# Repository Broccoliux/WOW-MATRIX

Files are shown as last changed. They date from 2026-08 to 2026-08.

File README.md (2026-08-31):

# WOW MATRIX
8x8x8 LED 3D Matrix

Built by Broccoli > ME <

## what this project is

This project is my WiFi controlled 8x8x8 LED cube thing and honestly it is kinda fire

The app folder is the browser controller and the frimware folder is the ESP32 S3 code and the tiny local web server running on the board

The 3D enclosure is done and the PCB is done too the only part missing on the enclosure is the LED mounts because I am gonna add those once I print the enclosure and test the fit

The main thing still missing right now is the firmware because that is the part that actually makes the cube run for real

## repo layout

```text
WOW MATRIX/
    app/
        index html       browser UI
        script js        3D cube logic controls animations WiFi sending
        style css        page styling and LED visuals
        firmware/        another firmware folder that exists in the app area
    frimware/
        platformio ini   ESP32 S3 PlatformIO config
        src/             ESP32 source files
        data/            files served by the ESP32 web server
    CAD/               cube design files and mechanical work
    imgs/              project images
    Matrix/            KiCad project and PCB related files
```

The real firmware folder is the root frimware not app firmware and that is the one that matters for flashing and deployment

## how the web app works

The browser creates 512 LED objects in JavaScript Each LED has

```text
x = 0 to 7
y = 0 to 7
z = 0 to 7
color = RGB
```

The data is stored in this order

```text
index = z * 64 + y * 8 + x
```

This is basically a visual 3D model of the cube CSS 3D transforms place each LED dot in space and dragging the viewport rotates the whole cube around X Y and Z The LEDs are rendered as little glowing bulbs with a highlight a colored center and a dark socket behind them

## controls in the page

### bulk selection

Use the LED table checkboxes to pick a bunch of voxels choose a color and hit Apply That updates the browser model and sends the frame to the ESP32 when the cube is connected

### animations

The current animation lineup is

- Rain drops fall down the Y axis in every X Z column
- Pulse the whole cube brightens and dims with the selected animation color
- Wave brightness moves through X Y and Z together
- Bouncing Ball a bright ball travels through the cube volume
- Lightning a quick flash path jumps through multiple voxels

The animation color picker is separate from the bulk selection color because changing the bulk color should not silently change the animation color That would be weird and annoying also some animations are still a little rough and I will clean them up later

### image mapper

Use the Image Mapper to load a photo or image The browser draws it into an 8x8 canvas and reads the pixels with Canvas getImageData

There are two modes

- 3D Volume each image pixel is copied across all 8 Z layers so a full 8x8 image can use all 512 LEDs
- Front Face each image pixel only appears on the front face so it uses up to 64 LEDs

Super dark or transparent pixels stay off The original RGB values are preserved per LED so the image does not get flattened into one single color

Loading an image also stops the current animation because the image frame has to stay on the cube

## ESP32 WiFi setup

The ESP32 S3 starts its own WiFi network not the home router Very on brand for a tiny cube project

```text
WiFi name LED_Cube_Controller
Password password123
ESP32 IP 192 168 4 1
```

The ESP32 also runs a DNS server If you type a hostname while connected to the cube WiFi it gets redirected to the board which is how the captive portal works on a lot of phones

If your phone does not auto open the controller just open this manually

```text
http://192 168 4 1
```

Some phones say the WiFi has no internet That is normal Just choose stay connected anyway The cube network is local and does not need internet for the controller to work

## how the ESP32 receives a frame

The browser sends a POST request to

```text
POST /api/frame
```

The request body is base64 text After decoding it has to contain exactly

```text
512 LEDs x 3 bytes = 1536 bytes
```

The bytes are sent in this order

```text
for z 0..7
    for y 0..7
        for x 0..7
            red green blue
```

Other API routes

```text
GET /api/status checks if the ESP32 is alive
POST /api/clear turns the stored frame off
```

The browser sends frames about 30 times per second while connected That limit is intentional so dragging the cube does not spam the ESP32 with a million requests

## upload the firmware and web page

You will need VS Code the PlatformIO extension and the ESP32 platform Open the root firmware folder

```text
F:\OneDrive\Desktop\cloned repos\WOW MATRIX\frimware
```

The board config is already in platformio ini

```ini
[env esp32 s3 devkitc 1]
platform = espressif32
board = esp32 s3 devkitc 1
framework = arduino
monitor_speed = 115200
```

First upload the files in data then upload the program

```bash
cd "F:\OneDrive\Desktop\cloned repos\WOW MATRIX\frimware"
pio run -t uploadfs
pio run -t upload
```

uploadfs pushes data index html data script js and data style css into the ESP32 LittleFS storage upload flashes the C++ firmware onto the board Both are needed

If you change anything in app copy the files into frimware data again before running uploadfs

```bash
copy "F:\OneDrive\Desktop\cloned repos\WOW MATRIX\app\index html" "F:\OneDrive\Desktop\cloned repos\WOW MATRIX\frimware\data\index html"
copy "F:\OneDrive\Desktop\cloned repos\WOW MATRIX\app\script js" "F:\OneDrive\Desktop\cloned repos\WOW MATRIX\frimware\data\script js"
copy "F:\OneDrive\Desktop\cloned repos\WOW MATRIX\app\style css" "F:\OneDrive\Desktop\cloned repos\WOW MATRIX\frimware\data\style css"
```

## what is done

The 3D enclosure is done and the PCB is done

The enclosure is missing the LED mounts for now because I am going to add those once I print the enclosure and test the fit

The main thing that is still missing is the firmware because that is the part that actually makes the cube do stuff in real life

## current status

What is working right now

- 3D 512 LED browser model
- mouse and touch rotation
- individual LED selection
- bulk color selection
- rain pulse wave ball and lightning animations
- custom animation color
- local image loading and 8x8 pixel sampling
- 3D volume image mode
- ESP32 access point setup
- captive portal routes
- status frame and clear HTTP API
- LittleFS web app serving

What is still missing

- final firmware logic to drive the real cube
- testing the real cube frame order against the physical wiring
- LED mounts on the enclosure after the print test

## final vibe

This project is made by Broccoli and that is the real energy

The software side is already pretty solid and the hardware side is basically in place now The 3D enclosure and PCB are done The only real big gap left is the firmware and that is where the focus needs to be next

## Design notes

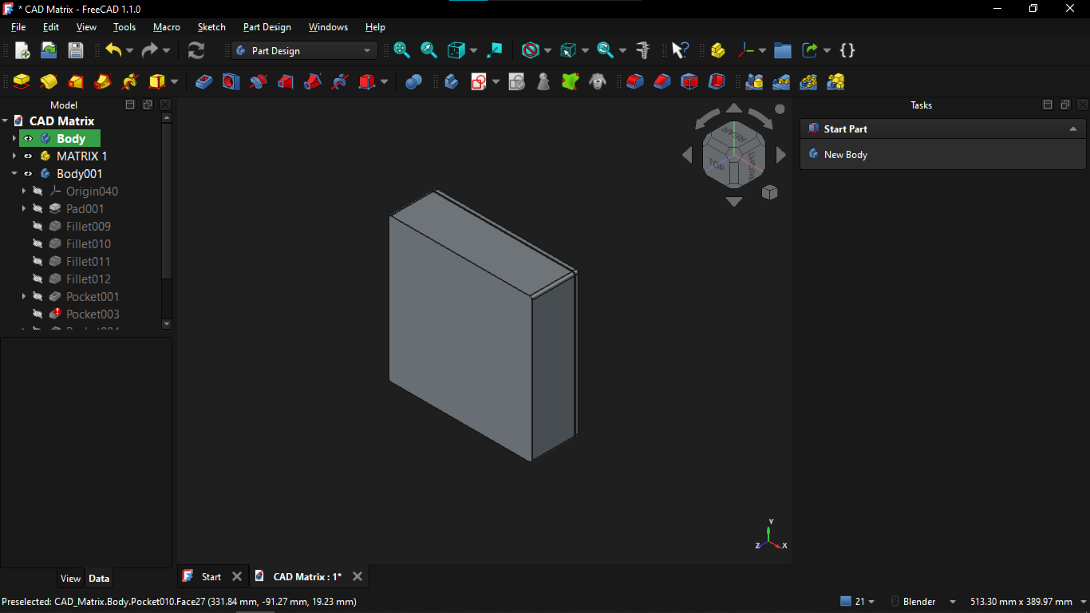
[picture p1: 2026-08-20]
imgs/CAD side.png

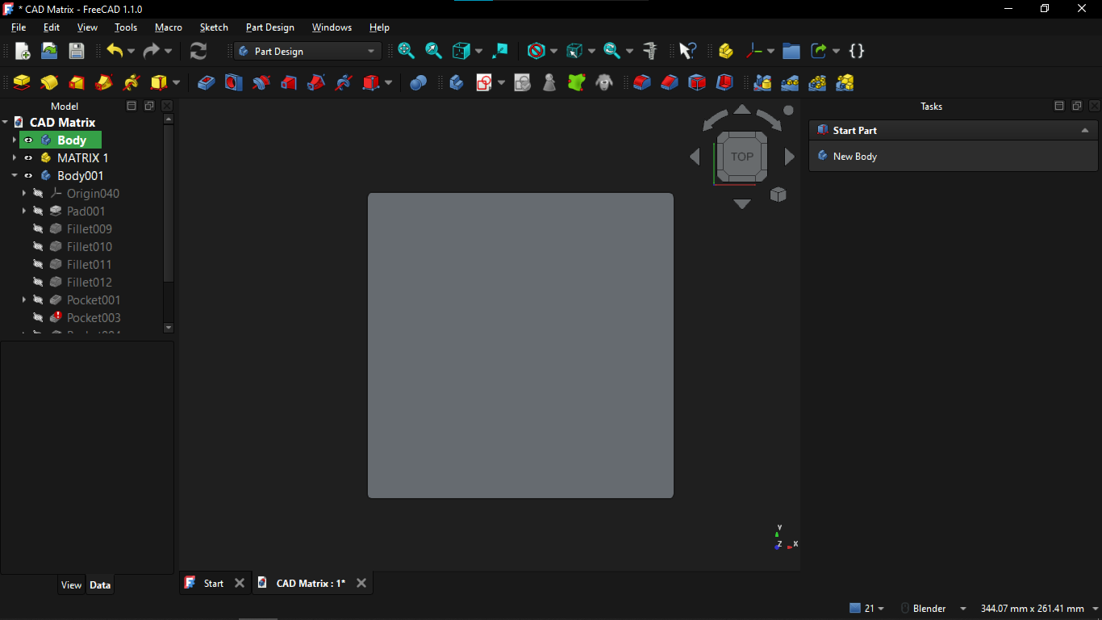
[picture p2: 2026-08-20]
imgs/CAD top.png

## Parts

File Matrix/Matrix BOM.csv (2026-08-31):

Name | price | link | amount | total
W25Q32JVSS | $1 | https://www.lcsc.com/product-detail/C82344.html | 1
ER_OLEDM0.91_1x-I2C | $4 | https://www.aliexpress.com/item/1005011783382489.html?curPageLogUid=u70x6dR5nU3C | 1
ESP32-S3 | $2.88 | https://www.lcsc.com/product-detail/rf-transceiver-ics_espressif-systems-esp32-s3_C2913192.html | 1
74HC138 | $1 | https://www.lcsc.com/product-detail/C5602.html?s_z=s_p_74HC138 | 1
74HC574N | $6 | https://www.lcsc.com/product-detail/C67579.html?s_z=n_q_74HC574N | 8
2N2219 | $7 | https://www.lcsc.com/product-detail/C37270941.html?s_z=n_q_2N2219 | 8
USB_C_Receptacle_USB2.0_16P | $0.6 | https://www.lcsc.com/product-detail/usb-connectors_shou-han-type-c16pin_C393939.html | 1
AP2112K-3.3 | $0.9 | https://www.lcsc.com/product-detail/C51118.html?s_z=n_q_AP2112K-3.3 | 1
Conn_01x08 | $5 | https://www.aliexpress.com/item/1005004839923910.html?curPageLogUid=xTL3mOFvH3BJ | 8
100 Capapstor of diff values | $5 |  | 100
100 resistor of diff vlaues | $5 |  | 100
5mm Led Diode RGB Light Emitting 4 Pin Common Anode Cathode Tricolor Multicolor Clear Diffused DIY PCB Lamp Bulb | $25 | https://www.aliexpress.com/item/1005003344498436.html?curPageLogUid=NNoxxVfOOImU | 512
 |  |  |  | $60

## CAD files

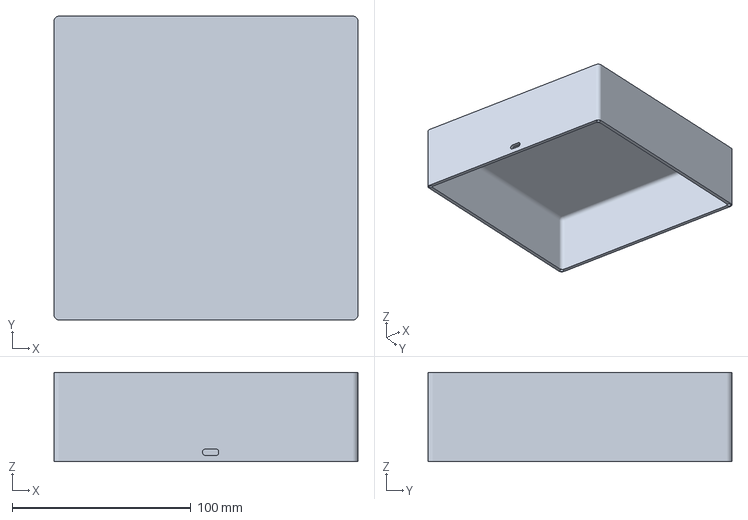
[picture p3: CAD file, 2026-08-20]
CAD/main box.3mf
170.0 x 170.0 x 50.0 mm

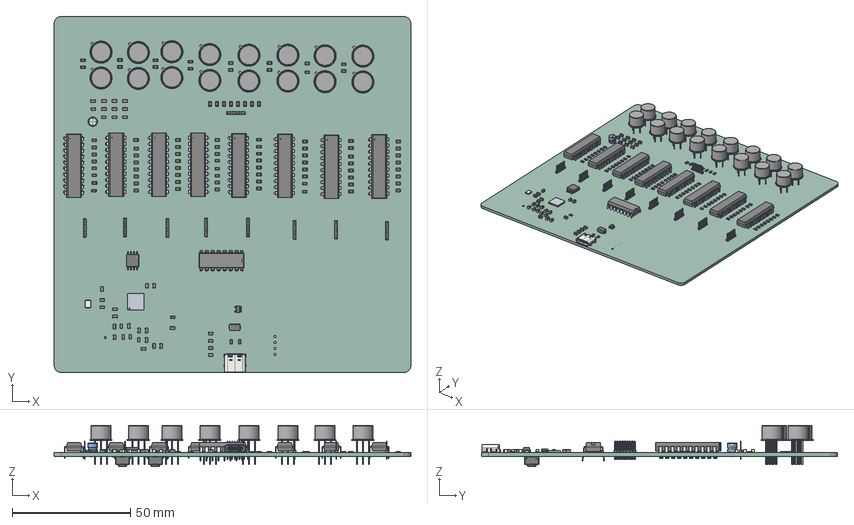
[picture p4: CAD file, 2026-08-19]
Matrix/MATRIX.step
151.0 x 150.7 x 17.5 mm
R_0805_2012Metric x 91
MATRIX 1.2.1
TO-39-3 x 16
SOT146-1_NXP x 8
C_0805_2012Metric x 32
PinHeader_1x08_P1.00mm_Vertical x 9
SOT-23-5
USB_C_Receptacle_GCT_USB4105-xx-A_16P_TopMnt_Horizontal
CP_Radial_D4.0mm_P1.50mm
L_0805_2012Metric x 4
D_SOD-923
Crystal_SMD_3225-4Pin_3.2x2.5mm
SOIC-8_5.3x5.3mm_P1.27mm
D_SMA
74HC138N_652
SW_SPST_PTS645Sx43SMTR92 x 2
Matrix_PCB

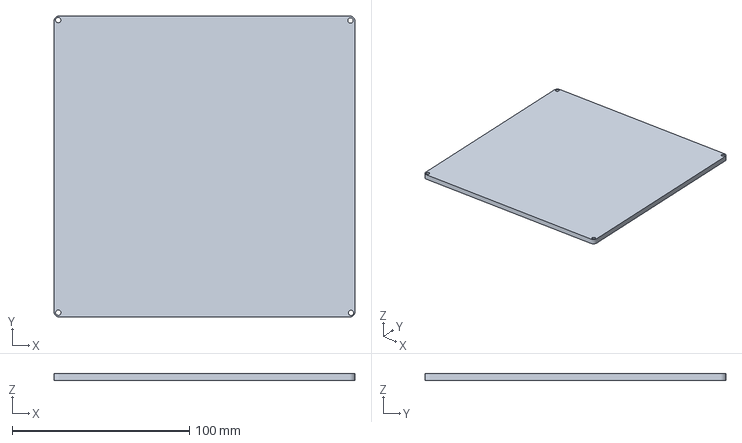
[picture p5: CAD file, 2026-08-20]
CAD/cover plate.3mf
170.0 x 170.0 x 4.00 mm

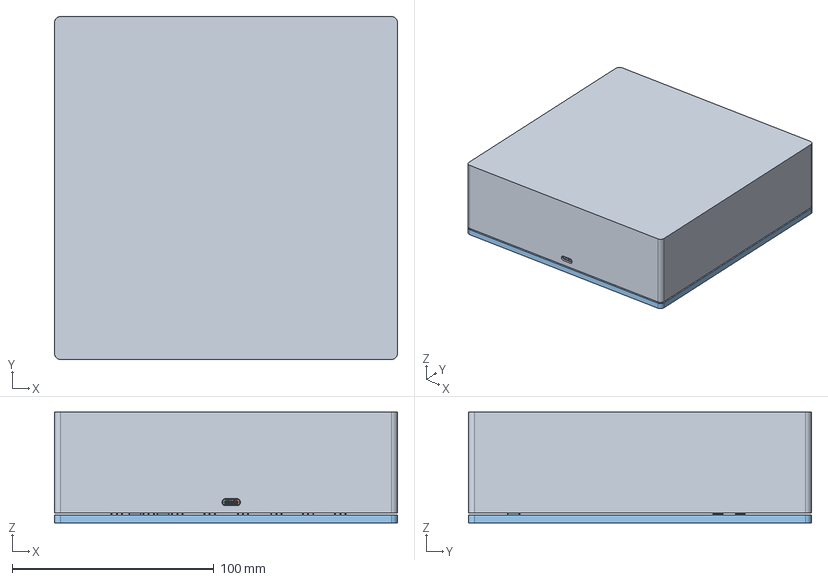
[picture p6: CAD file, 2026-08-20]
CAD/CAD Matrix.FCStd
170.0 x 170.0 x 55.0 mm
R_0805_2012Metric
MATRIX 1.2.1
MATRIX 1.2.001
MATRIX 1.2.002
MATRIX 1.2.003
MATRIX 1.2.004
MATRIX 1.2.005
MATRIX 1.2.006
MATRIX 1.2.007
MATRIX 1.2.008
MATRIX 1.2.009
MATRIX 1.2.010
MATRIX 1.2.011
MATRIX 1.2.012
MATRIX 1.2.013
MATRIX 1.2.014
MATRIX 1.2.015
MATRIX 1.2.016
MATRIX 1.2.017
MATRIX 1.2.018
MATRIX 1.2.019
MATRIX 1.2.020
MATRIX 1.2.021
MATRIX 1.2.022
MATRIX 1.2.023
MATRIX 1.2.024
MATRIX 1.2.025
MATRIX 1.2.026
MATRIX 1.2.027
MATRIX 1.2.028
MATRIX 1.2.029
MATRIX 1.2.030
MATRIX 1.2.031
MATRIX 1.2.032
MATRIX 1.2.033
MATRIX 1.2.034
MATRIX 1.2.035
MATRIX 1.2.036
MATRIX 1.2.037
MATRIX 1.2.038
MATRIX 1.2.039
MATRIX 1.2.040
MATRIX 1.2.041
MATRIX 1.2.042
MATRIX 1.2.043
MATRIX 1.2.044
MATRIX 1.2.045
MATRIX 1.2.046
MATRIX 1.2.047
MATRIX 1.2.048
MATRIX 1.2.049
MATRIX 1.2.050
MATRIX 1.2.051
MATRIX 1.2.052
MATRIX 1.2.053
MATRIX 1.2.054
MATRIX 1.2.055
MATRIX 1.2.056
MATRIX 1.2.057
MATRIX 1.2.058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

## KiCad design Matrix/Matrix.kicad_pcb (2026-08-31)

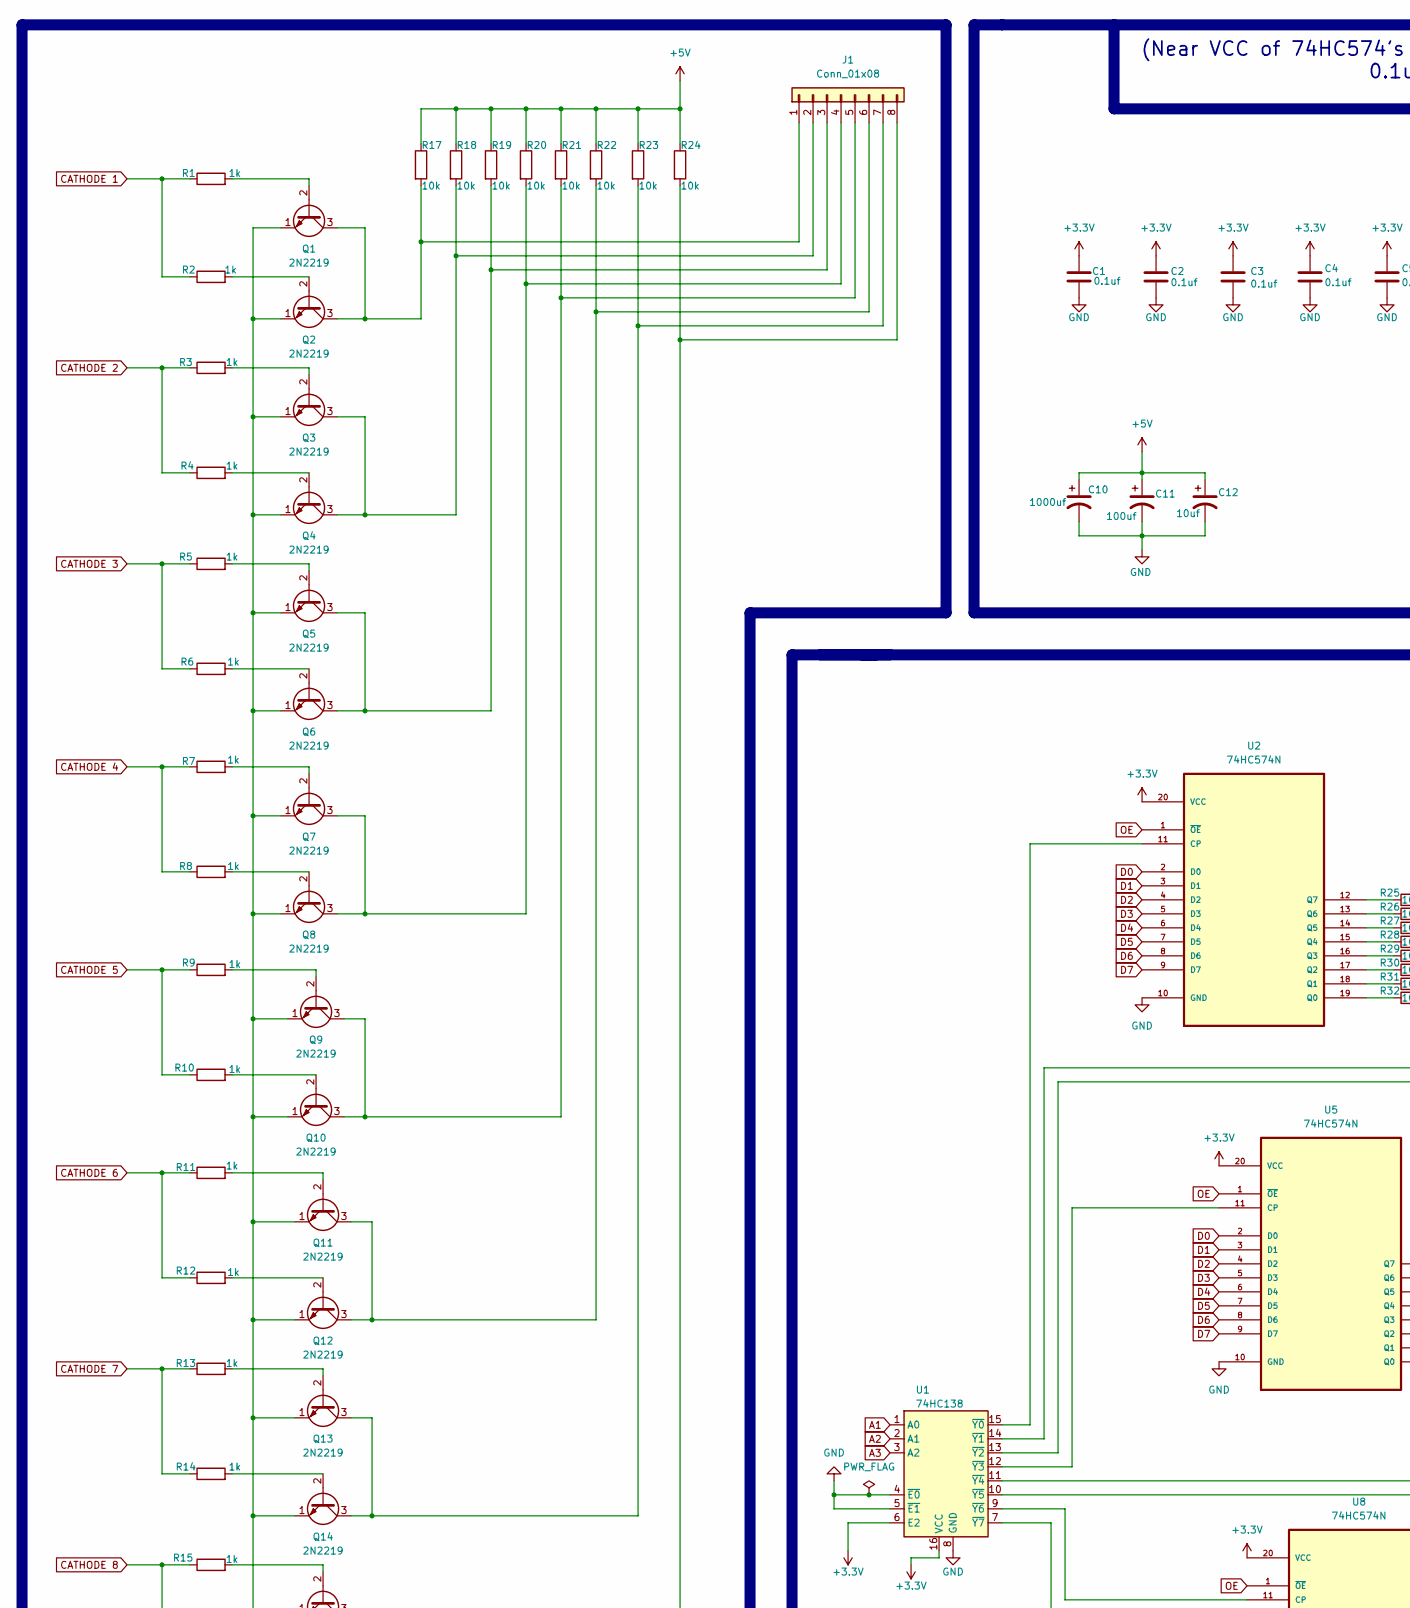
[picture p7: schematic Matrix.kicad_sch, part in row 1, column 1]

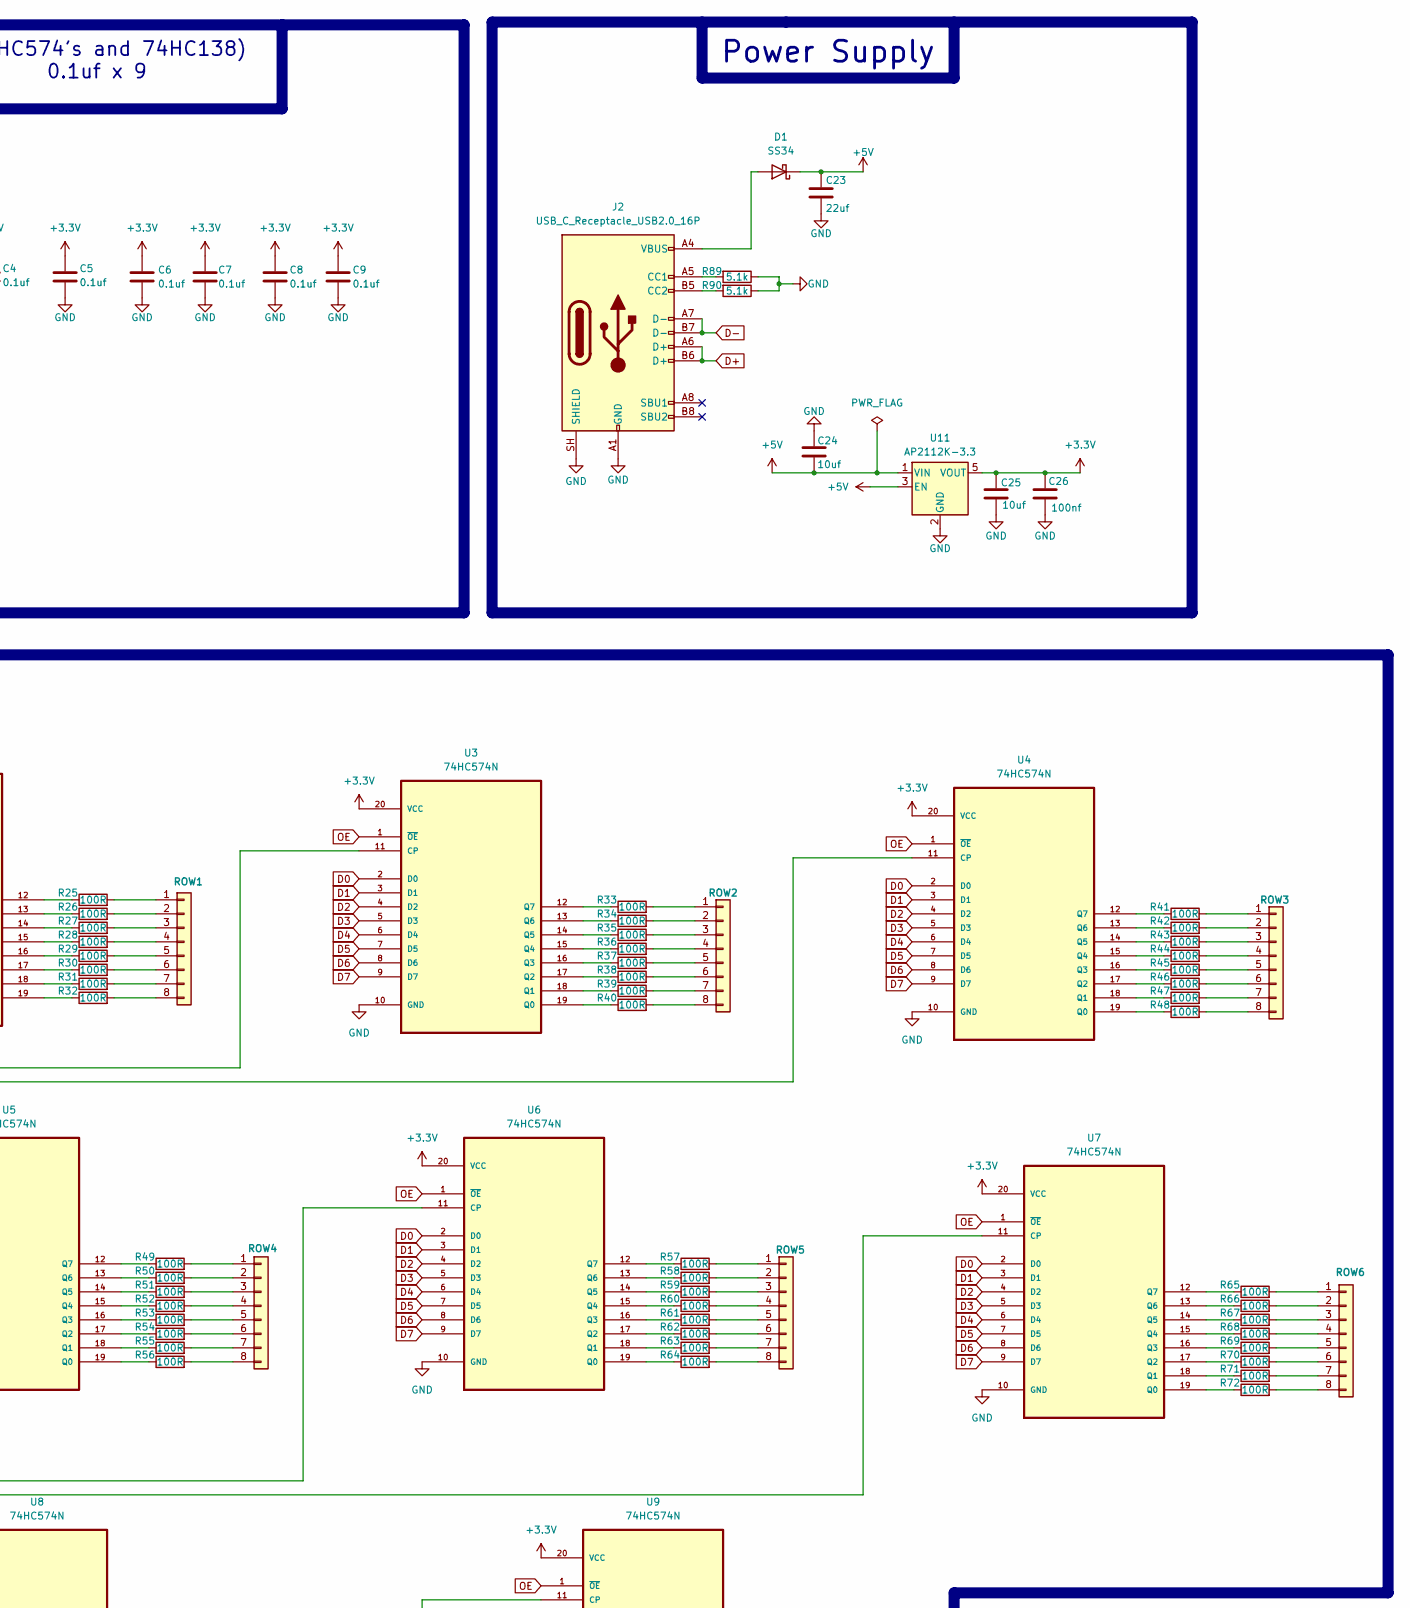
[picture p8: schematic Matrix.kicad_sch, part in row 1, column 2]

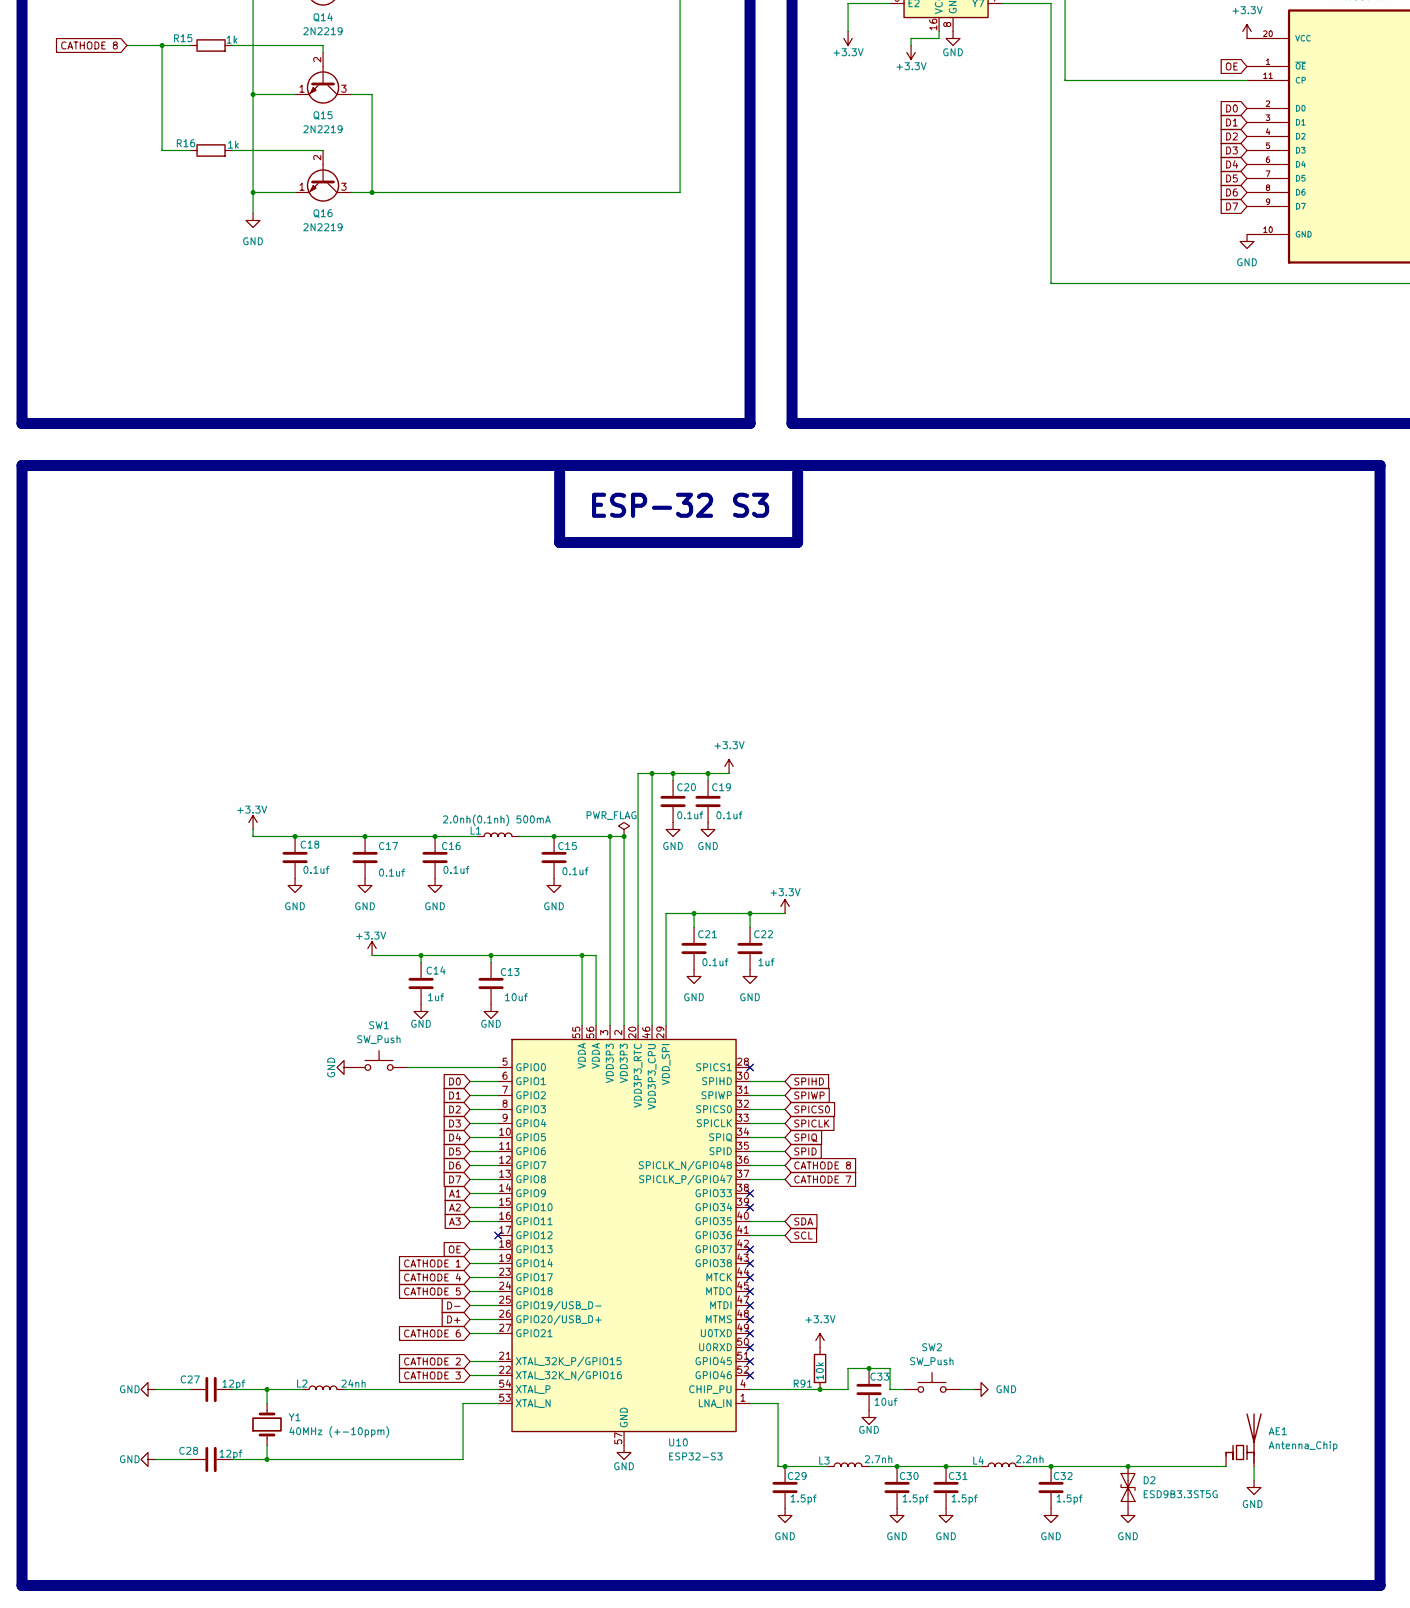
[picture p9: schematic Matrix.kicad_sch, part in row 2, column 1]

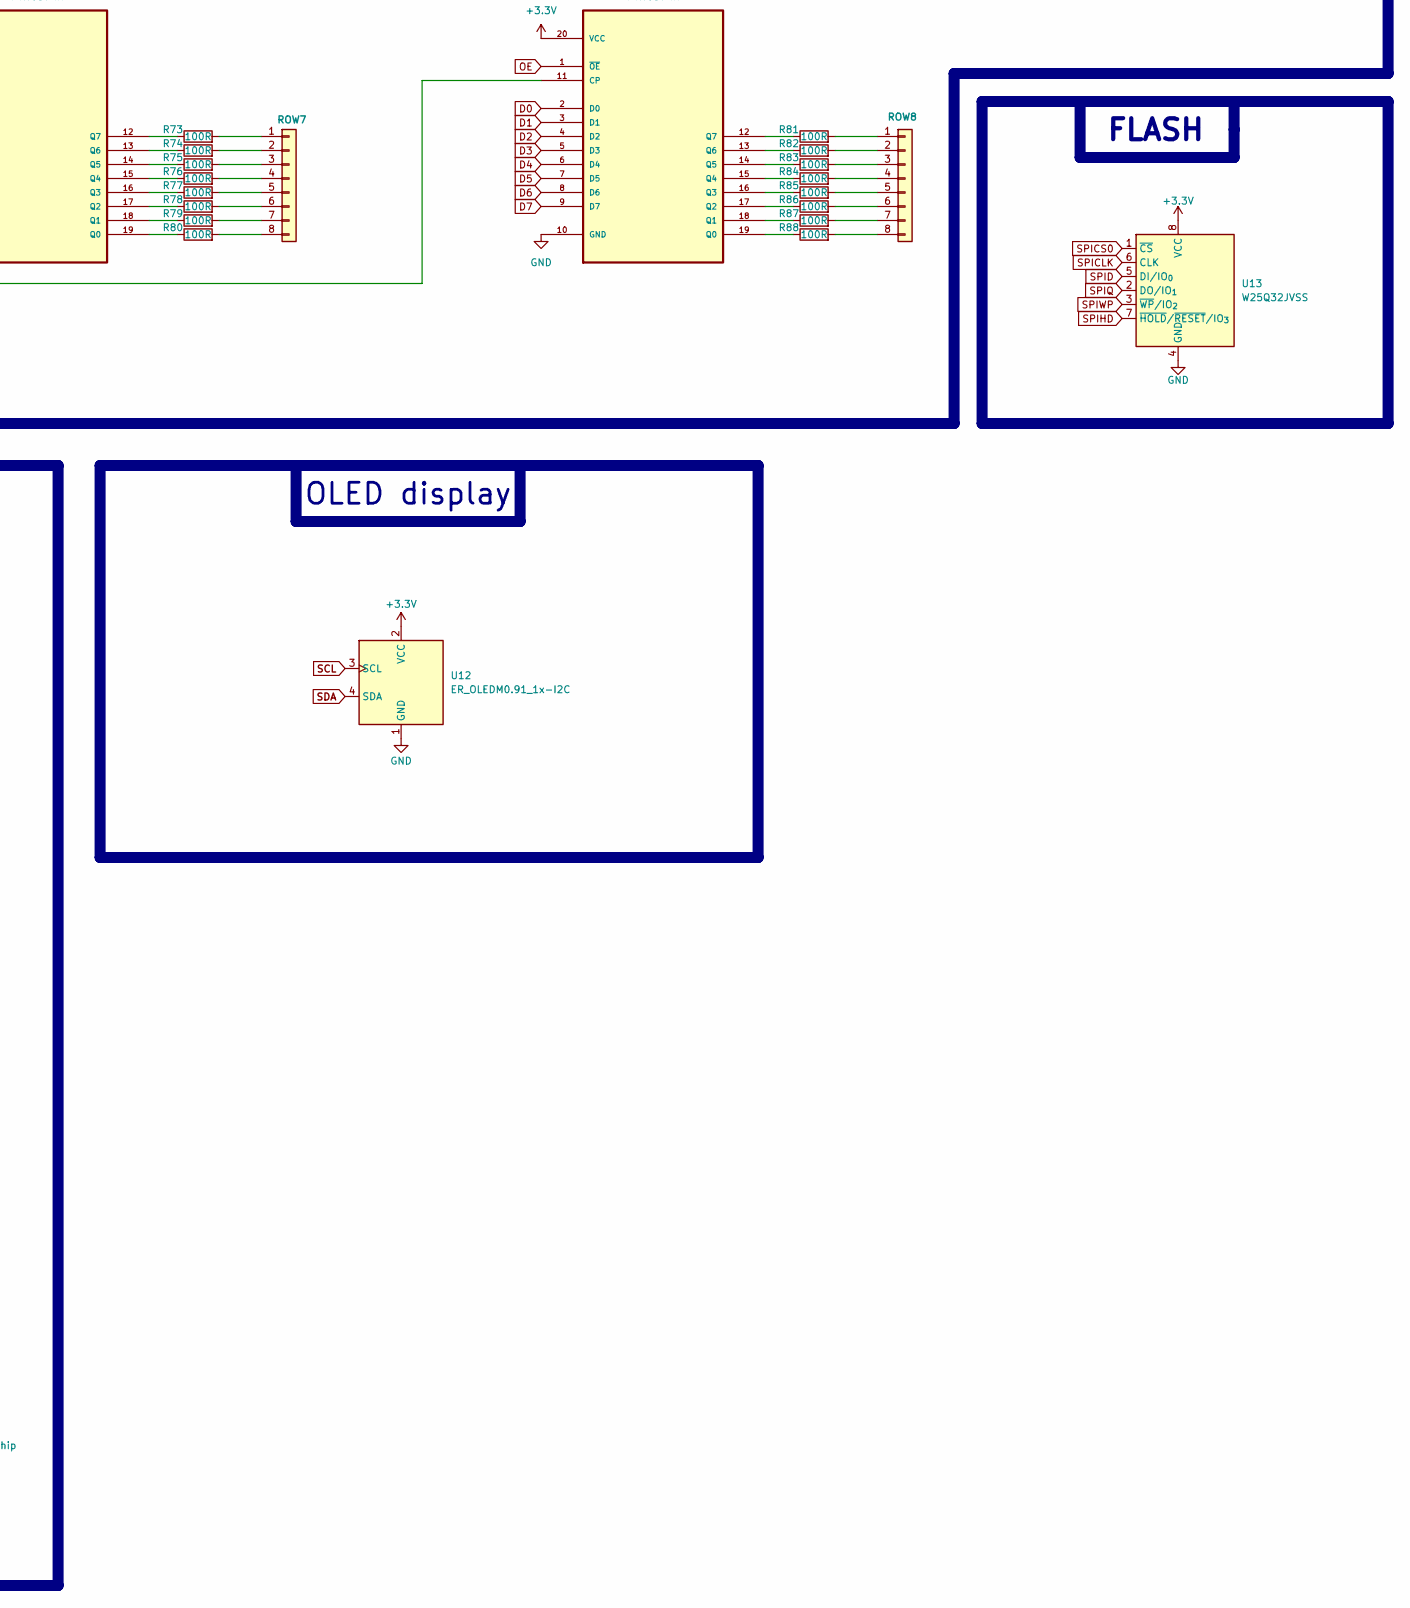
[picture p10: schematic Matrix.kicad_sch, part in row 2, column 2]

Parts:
AE1: Antenna_Chip; ANTC3216X60N
C1, C2, C3, C4, C5, C6, C7, C8, C9: 0.1uf; C_0805_2012Metric
C10: 1000uf; CP_Radial_D4.0mm_P1.50mm
C11: 100uf; C_0805_2012Metric_Pad1.18x1.45mm_HandSolder
C12, C13, C24, C25, C33: 10uf; C_0805_2012Metric_Pad1.18x1.45mm_HandSolder
C14, C22: 1uf; C_0805_2012Metric_Pad1.18x1.45mm_HandSolder
C15, C16, C17, C18, C19, C20, C21: 0.1uf; C_0805_2012Metric_Pad1.18x1.45mm_HandSolder
C23: 22uf; C_0805_2012Metric_Pad1.18x1.45mm_HandSolder
C26: 100nf; C_0805_2012Metric_Pad1.18x1.45mm_HandSolder
C27, C28: 12pf; C_0805_2012Metric_Pad1.18x1.45mm_HandSolder
C29, C30, C31, C32: 1.5pf; C_0805_2012Metric_Pad1.18x1.45mm_HandSolder
D1: SS34; D_SMA
D2: ESD9B3.3ST5G; D_SOD-923
J1: Conn_01x08; PinHeader_1x08_P1.00mm_Vertical
J2: USB_C_Receptacle_USB2.0_16P; USB_C_Receptacle_GCT_USB4105-xx-A_16P_TopMnt_Horizontal
L1: 2.0nh(0.1nh) 500mA; L_0805_2012Metric_Pad1.05x1.20mm_HandSolder
L2: 24nh; L_0805_2012Metric_Pad1.05x1.20mm_HandSolder
L3: 2.7nh; L_0805_2012Metric_Pad1.05x1.20mm_HandSolder
L4: 2.2nh; L_0805_2012Metric_Pad1.05x1.20mm_HandSolder
Q1, Q2, Q3, Q4, Q5, Q6, Q7, Q8, Q9, Q10, Q11, Q12, Q13, Q14, Q15, Q16: 2N2219; TO-39-3
R1, R2, R3, R4, R5, R6, R7, R8, R9, R10, R11, R12, R13, R14, R15, R16: 1k; R_0805_2012Metric_Pad1.20x1.40mm_HandSolder
R17, R18, R19, R20, R21, R22, R23, R24, R91: 10k; R_0805_2012Metric_Pad1.20x1.40mm_HandSolder
R25, R26, R27, R28, R29, R30, R31, R32, R33, R34, R35, R36, R37, R38, R39, R40, R41, R42, R43, R44, R45, R46, R47, R48, R49, R50, R51, R52, R53, R54, R55, R56, R57, R58, R59, R60, R61, R62, R63, R64, R65, R66, R67, R68, R69, R70, R71, R72, R73, R74, R75, R76, R77, R78, R79, R80, R81, R82, R83, R84, R85, R86, R87, R88: 100R; R_0805_2012Metric_Pad1.20x1.40mm_HandSolder
R89, R90: 5.1k; R_0805_2012Metric_Pad1.20x1.40mm_HandSolder
ROW1, ROW2, ROW3, ROW4, ROW5, ROW6, ROW7, ROW8: Conn_01x08; PinHeader_1x08_P1.00mm_Vertical
SW1, SW2: SW_Push; SW_SPST_PTS645Sx43SMTR92
U1: 74HC138; SOIC127P600X175-16N
U2, U3, U4, U5, U6, U7, U8, U9: 74HC574N; DIP254P762X420-20; MPN 74HC574N
U10: ESP32-S3; QFN-56-1EP_7x7mm_P0.4mm_EP4x4mm
U11: AP2112K-3.3; SOT-23-5
U12: ER_OLEDM0.91_1x-I2C
U13: W25Q32JVSS; SOIC-8_5.3x5.3mm_P1.27mm
Y1: 40MHz (+-10ppm); Crystal_SMD_3225-4Pin_3.2x2.5mm_HandSoldering

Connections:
+3.3V: C1.1, C2.1, C3.1, C4.1, C5.1, C6.1, C7.1, C8.1, C9.1, C13.1, C14.1, C16.1, C17.1, C18.1, C19.1, C20.1, C21.1, C22.1, C25.1, C26.1, L1.1, R91.1, U1.6 (E2), U1.16 (VCC), U2.20 (VCC), U3.20 (VCC), U4.20 (VCC), U5.20 (VCC), U6.20 (VCC), U7.20 (VCC), U8.20 (VCC), U9.20 (VCC), U10.20 (VDD3P3_RTC), U10.29 (VDD_SPI), U10.46 (VDD3P3_CPU), U10.55 (VDDA), U10.56 (VDDA), U11.5 (VOUT), U12.2 (VCC), U13.8 (VCC)
+5V: C10.1, C11.1, C12.1, C23.1, C24.2, D1.1 (K), R17.1, R18.1, R19.1, R20.1, R21.1, R22.1, R23.1, R24.1, U11.1 (VIN), U11.3 (EN)
A1: U1.1 (A0), U10.14 (GPIO9)
A2: U1.2 (A1), U10.15 (GPIO10)
A3: U1.3 (A2), U10.16 (GPIO11)
CATHODE 1: R1.1, R2.1, U10.19 (GPIO14)
CATHODE 2: R3.1, R4.1, U10.21 (XTAL_32K_P/GPIO15)
CATHODE 3: R5.1, R6.1, U10.22 (XTAL_32K_N/GPIO16)
CATHODE 4: R7.1, R8.1, U10.23 (GPIO17)
CATHODE 5: R9.1, R10.1, U10.24 (GPIO18)
CATHODE 6: R11.1, R12.1, U10.27 (GPIO21)
CATHODE 7: R13.1, R14.1, U10.37 (SPICLK_P/GPIO47)
CATHODE 8: R15.1, R16.1, U10.36 (SPICLK_N/GPIO48)
D0: U2.2 (D0), U3.2 (D0), U4.2 (D0), U5.2 (D0), U6.2 (D0), U7.2 (D0), U8.2 (D0), U9.2 (D0), U10.6 (GPIO1)
D1: U2.3 (D1), U3.3 (D1), U4.3 (D1), U5.3 (D1), U6.3 (D1), U7.3 (D1), U8.3 (D1), U9.3 (D1), U10.7 (GPIO2)
D2: U2.4 (D2), U3.4 (D2), U4.4 (D2), U5.4 (D2), U6.4 (D2), U7.4 (D2), U8.4 (D2), U9.4 (D2), U10.8 (GPIO3)
D3: U2.5 (D3), U3.5 (D3), U4.5 (D3), U5.5 (D3), U6.5 (D3), U7.5 (D3), U8.5 (D3), U9.5 (D3), U10.9 (GPIO4)
D4: U2.6 (D4), U3.6 (D4), U4.6 (D4), U5.6 (D4), U6.6 (D4), U7.6 (D4), U8.6 (D4), U9.6 (D4), U10.10 (GPIO5)
D5: U2.7 (D5), U3.7 (D5), U4.7 (D5), U5.7 (D5), U6.7 (D5), U7.7 (D5), U8.7 (D5), U9.7 (D5), U10.11 (GPIO6)
D6: U2.8 (D6), U3.8 (D6), U4.8 (D6), U5.8 (D6), U6.8 (D6), U7.8 (D6), U8.8 (D6), U9.8 (D6), U10.12 (GPIO7)
D7: U2.9 (D7), U3.9 (D7), U4.9 (D7), U5.9 (D7), U6.9 (D7), U7.9 (D7), U8.9 (D7), U9.9 (D7), U10.13 (GPIO8)
D+: J2.A6 (D+), J2.B6 (D+), U10.26 (GPIO20/USB_D+)
D-: J2.A7 (D-), J2.B7 (D-), U10.25 (GPIO19/USB_D-)
GND: AE1.2 (PCB_Trace), C1.2, C2.2, C3.2, C4.2, C5.2, C6.2, C7.2, C8.2, C9.2, C10.2, C11.2, C12.2, C13.2, C14.2, C15.2, C16.2, C17.2, C18.2, C19.2, C20.2, C21.2, C22.2, C23.2, C24.1, C25.2, C26.2, C27.1, C28.1, C29.2, C30.2, C31.2, C32.2, C33.2, D2.1 (A1), J2.A1 (GND), J2.A12 (GND), J2.B1 (GND), J2.B12 (GND), J2.SH (SHIELD), Q1.1 (E), Q2.1 (E), Q3.1 (E), Q4.1 (E), Q5.1 (E), Q6.1 (E), Q7.1 (E), Q8.1 (E), Q9.1 (E), Q10.1 (E), Q11.1 (E), Q12.1 (E), Q13.1 (E), Q14.1 (E), Q15.1 (E), Q16.1 (E), R89.1, R90.1, SW1.1, SW2.2, U1.4 (~E0), U1.5 (~E1), U1.8 (GND), U2.10 (GND), U3.10 (GND), U4.10 (GND), U5.10 (GND), U6.10 (GND), U7.10 (GND), U8.10 (GND), U9.10 (GND), U10.57 (GND), U11.2 (GND), U12.1 (GND), U13.4 (GND)
unnamed: AE1.1 (FEED), C32.1, D2.2 (A2), L4.2
unnamed: C15.1, L1.2, U10.2 (VDD3P3), U10.3 (VDD3P3)
unnamed: C27.2, L2.1, Y1.2
unnamed: C30.1, C31.1, L3.2, L4.1
unnamed: D1.2 (A), J2.A4 (VBUS), J2.A9 (VBUS), J2.B4 (VBUS), J2.B9 (VBUS)
unnamed: J1.1, Q1.3 (C), Q2.3 (C), R17.2
unnamed: J1.2, Q3.3 (C), Q4.3 (C), R18.2
unnamed: J1.3, Q5.3 (C), Q6.3 (C), R19.2
unnamed: J1.4, Q7.3 (C), Q8.3 (C), R20.2
unnamed: J1.5, Q9.3 (C), Q10.3 (C), R21.2
unnamed: J1.6, Q11.3 (C), Q12.3 (C), R22.2
unnamed: J1.7, Q13.3 (C), Q14.3 (C), R23.2
unnamed: J1.8, Q15.3 (C), Q16.3 (C), R24.2
unnamed: J2.A5 (CC1), R89.2
unnamed: J2.B5 (CC2), R90.2
unnamed: Q1.2 (B), R1.2
unnamed: Q2.2 (B), R2.2
unnamed: Q3.2 (B), R3.2
unnamed: Q4.2 (B), R4.2
unnamed: Q5.2 (B), R5.2
unnamed: Q6.2 (B), R6.2
unnamed: Q7.2 (B), R7.2
unnamed: Q8.2 (B), R8.2
unnamed: Q9.2 (B), R9.2
unnamed: Q10.2 (B), R10.2
unnamed: Q11.2 (B), R11.2
unnamed: Q12.2 (B), R12.2
unnamed: Q13.2 (B), R13.2
unnamed: Q14.2 (B), R14.2
unnamed: Q15.2 (B), R15.2
unnamed: Q16.2 (B), R16.2
unnamed: R25.2, ROW1.1
unnamed: R26.2, ROW1.2
unnamed: R27.2, ROW1.3
unnamed: R28.2, ROW1.4
unnamed: R29.2, ROW1.5
unnamed: R30.2, ROW1.6
unnamed: R31.2, ROW1.7
unnamed: R32.2, ROW1.8
unnamed: R33.2, ROW2.1
unnamed: R34.2, ROW2.2
unnamed: R35.2, ROW2.3
unnamed: R36.2, ROW2.4
unnamed: R37.2, ROW2.5
unnamed: R38.2, ROW2.6
unnamed: R39.2, ROW2.7
unnamed: R40.2, ROW2.8
unnamed: R41.2, ROW3.1
unnamed: R42.2, ROW3.2
unnamed: R43.2, ROW3.3
unnamed: R44.2, ROW3.4
unnamed: R45.2, ROW3.5
unnamed: R46.2, ROW3.6
unnamed: R47.2, ROW3.7
unnamed: R48.2, ROW3.8
unnamed: R49.2, ROW4.1
unnamed: R50.2, ROW4.2
unnamed: R51.2, ROW4.3
unnamed: R52.2, ROW4.4
unnamed: R53.2, ROW4.5
unnamed: R54.2, ROW4.6
unnamed: R55.2, ROW4.7
unnamed: R56.2, ROW4.8
unnamed: R57.2, ROW5.1
unnamed: R58.2, ROW5.2
unnamed: R59.2, ROW5.3
unnamed: R60.2, ROW5.4
unnamed: R61.2, ROW5.5
unnamed: R62.2, ROW5.6
unnamed: R63.2, ROW5.7
unnamed: R64.2, ROW5.8
unnamed: R65.2, ROW6.1
unnamed: R66.2, ROW6.2
unnamed: R67.2, ROW6.3
unnamed: R68.2, ROW6.4
unnamed: R69.2, ROW6.5
unnamed: R70.2, ROW6.6
unnamed: R71.2, ROW6.7
unnamed: R72.2, ROW6.8
unnamed: R73.2, ROW7.1
unnamed: R74.2, ROW7.2
unnamed: R75.2, ROW7.3
unnamed: R76.2, ROW7.4
unnamed: R77.2, ROW7.5
unnamed: R78.2, ROW7.6
unnamed: R79.2, ROW7.7
unnamed: R80.2, ROW7.8
unnamed: R81.2, ROW8.1
unnamed: R82.2, ROW8.2
unnamed: R83.2, ROW8.3
unnamed: R84.2, ROW8.4
unnamed: R85.2, ROW8.5
unnamed: R86.2, ROW8.6
unnamed: R87.2, ROW8.7
unnamed: R88.2, ROW8.8
unnamed: U1.15 (~Y0), U2.11 (CP)
unnamed: U1.14 (~Y1), U3.11 (CP)
unnamed: U1.13 (~Y2), U4.11 (CP)
unnamed: U1.12 (~Y3), U5.11 (CP)
unnamed: U1.11 (~Y4), U6.11 (CP)
unnamed: U1.10 (~Y5), U7.11 (CP)
unnamed: U1.9 (~Y6), U8.11 (CP)
unnamed: U1.7 (~Y7), U9.11 (CP)
unnamed: R32.1, U2.19 (Q0)
unnamed: R31.1, U2.18 (Q1)
unnamed: R30.1, U2.17 (Q2)
unnamed: R29.1, U2.16 (Q3)
unnamed: R28.1, U2.15 (Q4)
unnamed: R27.1, U2.14 (Q5)
unnamed: R26.1, U2.13 (Q6)
unnamed: R25.1, U2.12 (Q7)
unnamed: R40.1, U3.19 (Q0)
unnamed: R39.1, U3.18 (Q1)
unnamed: R38.1, U3.17 (Q2)
unnamed: R37.1, U3.16 (Q3)
unnamed: R36.1, U3.15 (Q4)
unnamed: R35.1, U3.14 (Q5)
unnamed: R34.1, U3.13 (Q6)
unnamed: R33.1, U3.12 (Q7)
unnamed: R48.1, U4.19 (Q0)
unnamed: R47.1, U4.18 (Q1)
unnamed: R46.1, U4.17 (Q2)
unnamed: R45.1, U4.16 (Q3)
unnamed: R44.1, U4.15 (Q4)
unnamed: R43.1, U4.14 (Q5)
unnamed: R42.1, U4.13 (Q6)
unnamed: R41.1, U4.12 (Q7)
unnamed: R56.1, U5.19 (Q0)
unnamed: R55.1, U5.18 (Q1)
unnamed: R54.1, U5.17 (Q2)
unnamed: R53.1, U5.16 (Q3)
unnamed: R52.1, U5.15 (Q4)
unnamed: R51.1, U5.14 (Q5)
unnamed: R50.1, U5.13 (Q6)
unnamed: R49.1, U5.12 (Q7)
unnamed: R64.1, U6.19 (Q0)
unnamed: R63.1, U6.18 (Q1)
unnamed: R62.1, U6.17 (Q2)
unnamed: R61.1, U6.16 (Q3)
unnamed: R60.1, U6.15 (Q4)
unnamed: R59.1, U6.14 (Q5)
unnamed: R58.1, U6.13 (Q6)
unnamed: R57.1, U6.12 (Q7)
unnamed: R72.1, U7.19 (Q0)
unnamed: R71.1, U7.18 (Q1)
unnamed: R70.1, U7.17 (Q2)
unnamed: R69.1, U7.16 (Q3)
unnamed: R68.1, U7.15 (Q4)
unnamed: R67.1, U7.14 (Q5)
unnamed: R66.1, U7.13 (Q6)
unnamed: R65.1, U7.12 (Q7)
unnamed: R80.1, U8.19 (Q0)
unnamed: R79.1, U8.18 (Q1)
unnamed: R78.1, U8.17 (Q2)
unnamed: R77.1, U8.16 (Q3)
unnamed: R76.1, U8.15 (Q4)
unnamed: R75.1, U8.14 (Q5)
unnamed: R74.1, U8.13 (Q6)
unnamed: R73.1, U8.12 (Q7)
unnamed: R88.1, U9.19 (Q0)
unnamed: R87.1, U9.18 (Q1)
unnamed: R86.1, U9.17 (Q2)
unnamed: R85.1, U9.16 (Q3)
unnamed: R84.1, U9.15 (Q4)
unnamed: R83.1, U9.14 (Q5)
unnamed: R82.1, U9.13 (Q6)
unnamed: R81.1, U9.12 (Q7)
unnamed: C33.1, R91.2, SW2.1, U10.4 (CHIP_PU)
unnamed: SW1.2, U10.5 (GPIO0)
unnamed: C29.1, L3.1, U10.1 (LNA_IN)
unnamed: C28.2, U10.53 (XTAL_N), Y1.1
unnamed: L2.2, U10.54 (XTAL_P)
OE: U2.1 (~OE), U3.1 (~OE), U4.1 (~OE), U5.1 (~OE), U6.1 (~OE), U7.1 (~OE), U8.1 (~OE), U9.1 (~OE), U10.18 (GPIO13)
SCL: U10.41 (GPIO36), U12.3 (SCL)
SDA: U10.40 (GPIO35), U12.4 (SDA)
SPICLK: U10.33 (SPICLK), U13.6 (CLK)
SPICS0: U10.32 (SPICS0), U13.1 (~CS)
SPID: U10.35 (SPID), U13.5 (DI/IO_{0})
SPIHD: U10.30 (SPIHD), U13.7 (~HOLD/~RESET/IO_{3})
SPIQ: U10.34 (SPIQ), U13.2 (DO/IO_{1})
SPIWP: U10.31 (SPIWP), U13.3 (~WP/IO_{2})

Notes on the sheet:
(Near VCC of 74HC574's and 74HC138) 0.1uf x 9
Power Supply
FLASH
ESP-32 S3
OLED display

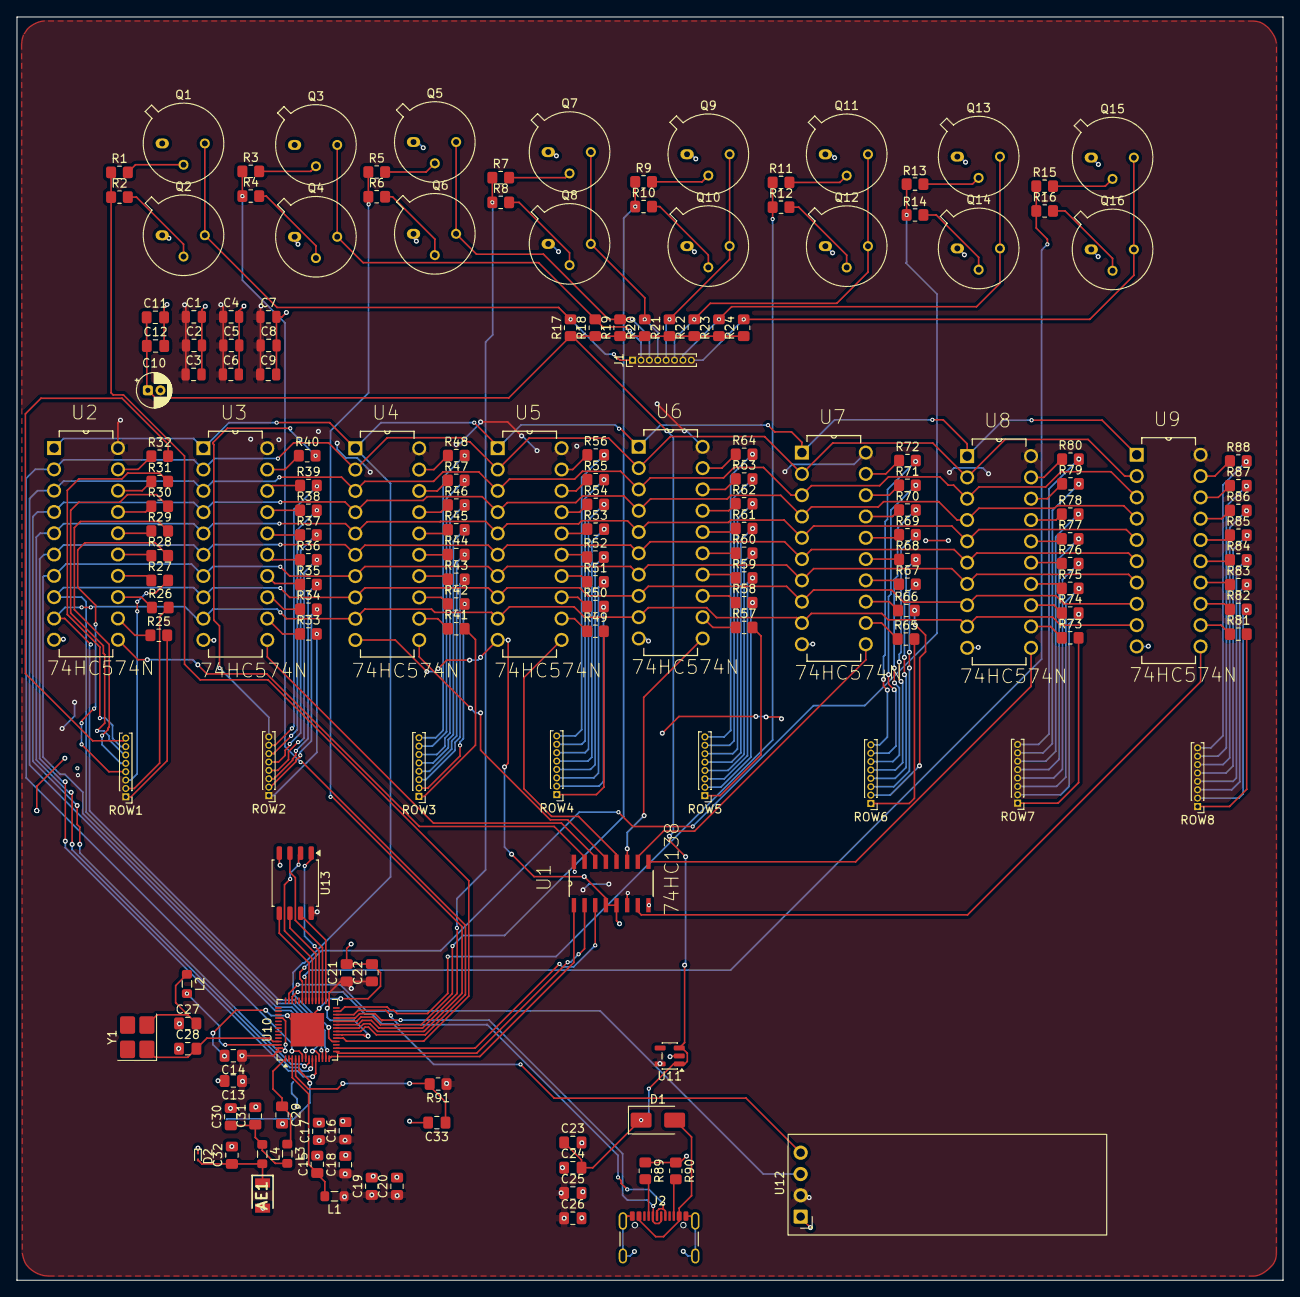
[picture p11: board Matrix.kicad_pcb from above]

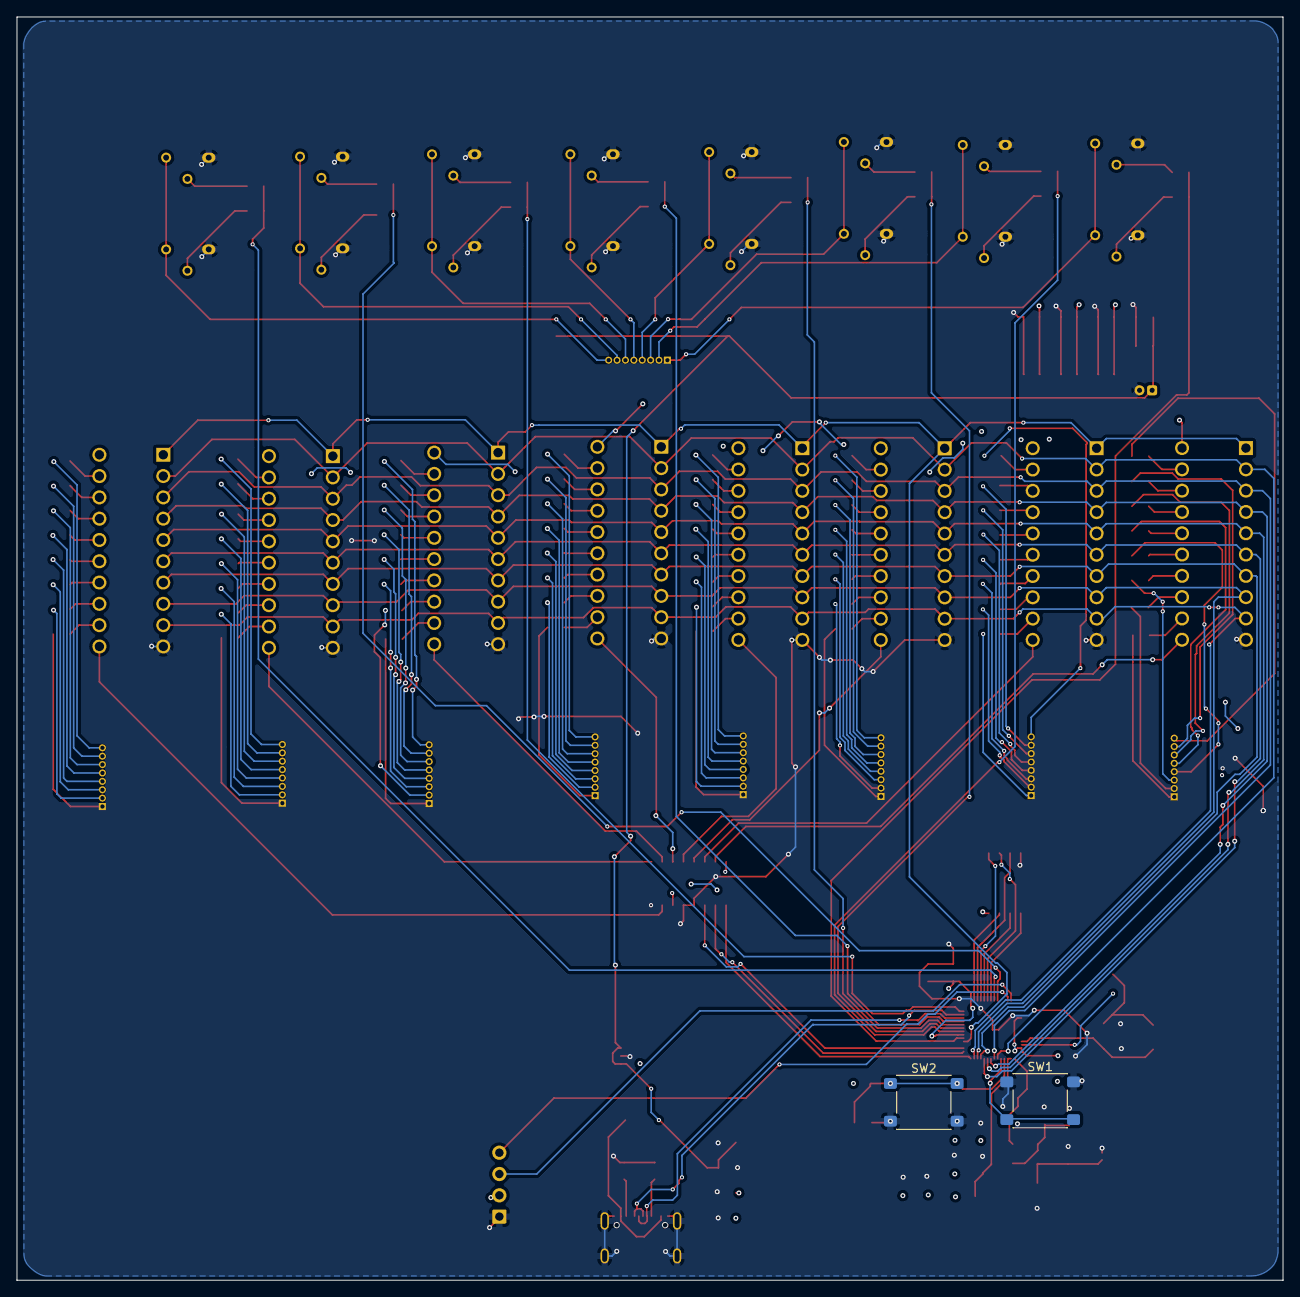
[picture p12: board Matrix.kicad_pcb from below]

Board: 2 copper layers, 151.0 x 150.7 mm, 173 parts (2 on the bottom side), 205 nets.

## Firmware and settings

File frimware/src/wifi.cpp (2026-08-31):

#include <Arduino.h>
#include <WiFi.h>
#include <WebServer.h>
#include <DNSServer.h>
#include <LittleFS.h>
#include <mbedtls/base64.h>
#include "cube.h"
#include "wifi_controller.h"

const char *ssid = "LED_Cube_Controller";
const char *password = "password123";
WebServer server(80);
DNSServer dnsServer;

static String contentType(const String &path)
{
  if (path.endsWith(".html")) return "text/html";
  if (path.endsWith(".css")) return "text/css";
  if (path.endsWith(".js")) return "application/javascript";
  if (path.endsWith(".png")) return "image/png";
  if (path.endsWith(".jpg") || path.endsWith(".jpeg")) return "image/jpeg";
  if (path.endsWith(".svg")) return "image/svg+xml";
  return "text/plain";
}

static void allowCors()
{
  server.sendHeader("Access-Control-Allow-Origin", "*");
  server.sendHeader("Access-Control-Allow-Methods", "GET,POST,OPTIONS");
  server.sendHeader("Access-Control-Allow-Headers", "Content-Type");
}

static void handleOptions()
{
  allowCors();
  server.send(204);
}

static void handleStatus()
{
  allowCors();
  server.send(200, "application/json", "{\"ok\":true,\"device\":\"ESP32-S3 LED Cube\",\"size\":8}");
}

static void handleFrame()
{
  allowCors();
  if (server.method() != HTTP_POST)
  {
    server.send(400, "application/json", "{\"ok\":false,\"error\":\"Expected a base64 frame POST\"}");
    return;
  }

  const String encoded = server.arg("plain");
  uint8_t frame[8 * 8 * 8 * 3];
  size_t decodedLength = 0;
  const int result = mbedtls_base64_decode(frame, sizeof(frame), &decodedLength,
                                           reinterpret_cast<const uint8_t *>(encoded.c_str()), encoded.length());

  if (result != 0 || decodedLength != sizeof(frame) || !cube_set_frame(frame, decodedLength))
  {
    server.send(400, "application/json", "{\"ok\":false,\"error\":\"Frame must be base64 encoded and contain exactly 1536 bytes\"}");
    return;
  }

  server.send(200, "application/json", "{\"ok\":true}");
}

static void handleClear()
{
  cube_clear();
  cube_refresh();
  allowCors();
  server.send(200, "application/json", "{\"ok\":true}");
}

static void servePortal()
{
  if (LittleFS.exists("/index.html"))
  {
    File file = LittleFS.open("/index.html", "r");
    server.sendHeader("Cache-Control", "no-store");
    server.send(200, "text/html", file.readString());
    file.close();
    return;
  }

  server.send(500, "text/plain", "Controller app is missing from LittleFS data.");
}

static void handleFileRequest()
{
  String path = server.uri();
  if (path == "/") path = "/index.html";

  if (LittleFS.exists(path))
  {
    File file = LittleFS.open(path, "r");
    server.streamFile(file, contentType(path));
    file.close();
    return;
  }

  servePortal();
}

void wifi_init_ap()
{
  Serial.println("Setting up Access Point...");

  if (!LittleFS.begin(true))
  {
    Serial.println("LittleFS mount failed");
  }

  WiFi.mode(WIFI_AP);
  WiFi.softAP(ssid, password);
  dnsServer.start(53, "*", WiFi.softAPIP());

  IPAddress myIP = WiFi.softAPIP();
  Serial.print("AP IP address: ");
  Serial.println(myIP);
}

void wifi_server_begin()
{
  server.on("/api/status", HTTP_GET, handleStatus);
  server.on("/api/frame", HTTP_POST, handleFrame);
  server.on("/api/clear", HTTP_POST, handleClear);
  server.on("/api/status", HTTP_OPTIONS, handleOptions);
  server.on("/api/frame", HTTP_OPTIONS, handleOptions);
  server.on("/api/clear", HTTP_OPTIONS, handleOptions);
  server.on("/generate_204", HTTP_GET, servePortal);
  server.on("/hotspot-detect.html", HTTP_GET, servePortal);
  server.on("/connecttest.txt", HTTP_GET, servePortal);
  server.on("/ncsi.txt", HTTP_GET, servePortal);
  server.on("/fwlink", HTTP_GET, servePortal);
  server.onNotFound(handleFileRequest);
  server.begin();
  Serial.println("HTTP API started on port 80");
}

void wifi_server_handle()
{
  dnsServer.processNextRequest();
  server.handleClient();
}

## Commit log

2026-08-19 Create CAD Matrix.FCStd
    [CAD Matrix.FCStd]
2026-08-20 Create CAD Matrix.20260820-071338.FCBak
2026-08-20 Create cover plate.3mf
    [cover plate.3mf]
2026-08-20 Create main box.3mf
    [main box.3mf]
2026-08-20 Create CAD side.png
2026-08-20 Create CAD top.png
2026-08-20 Create CAD ultra side.png
2026-08-31 Create Matrix BOM.csv
    [Matrix BOM.csv]
2026-11-02 Create 3d pcb.png
2026-11-02 Create schematic .png
